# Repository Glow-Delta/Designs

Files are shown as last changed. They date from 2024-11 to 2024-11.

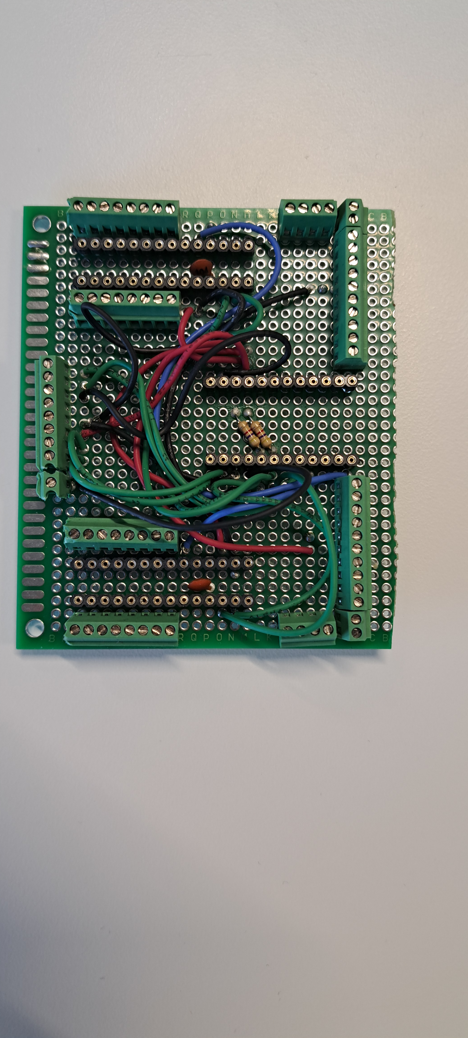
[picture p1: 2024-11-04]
Design Top component/20241104_130950.jpg

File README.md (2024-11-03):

# Designs
Repo for all the project design files, no code

When a design change is made it isn't final until its written down and reviewed. To submit a design change: make a new branch, commit the design changes and create a pull request into the main branch. Only after review has gone through will the change go through.

Designs to submit before monday 14:00:
-  [ ] Print board design
-  [ ] Updated C4
-  [ ] Network cableing
-  [ ] LED cylinder component
-  [ ] power supply component

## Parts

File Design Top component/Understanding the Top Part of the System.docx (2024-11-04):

Understanding the Top Part of the System: Movement Detection Module

Goal of the System

The primary goal of the top part of the system is to detect movement from end users using a series of sensors. This functionality allows the system to monitor and respond to changes in the environment based on user interaction or movement.

Components Inside

1. 16 Ultrasonic Sensors
  - These sensors are strategically positioned to cover a wide detection area. Each sensor is capable of emitting ultrasonic sound waves and measuring the time it takes for the waves to bounce back after hitting an object, enabling accurate distance measurements and movement detection.
2. Printed Circuit Board (PCB)
  - The printed circuit board acts as the foundation for connecting and integrating all electronic components. It ensures organized wiring and stable connectivity between sensors and microcontrollers.
3. Pro Micro Microcontroller
  - The Pro Micro serves as the main microcontroller, managing data collection from the sensors and processing input. It sends data through serial communication to the main server or the next processing stage.
4. MCP23017 I2C Port Expander
  - The MCP23017 is used to expand the number of general-purpose input/output (GPIO) pins available, as the Pro Micro itself has limited GPIO capability. This expander ensures that all 16 sensors can be connected and managed efficiently.

How It Works

1. Sensor Activation: Each of the 16 ultrasonic sensors is connected to the system through the PCB and controlled via the Pro Micro. These sensors emit ultrasonic pulses and wait for the return signal to measure the distance to any object in front of them.
2. Data Processing: The Pro Micro collects the distance data from the sensors. If movement is detected (i.e., a change in the distance data that indicates a user's presence or motion), the microcontroller processes this input.
3. GPIO Management: The MCP23017 I2C Port Expander plays a crucial role in handling the signals from all 16 sensors. By expanding the Pro Micro's limited number of GPIO pins, the MCP23017 allows simultaneous connections for all sensors without compromising data integrity.
4. Communication: Processed data from the Pro Micro is transmitted via serial communication to a server for further action. This data transfer ensures that detected movement can trigger various responses, such as activating alerts, updating displays, or executing other system operations.
5. LED Strip Activation: When movement is detected, the system also sends a signal to connected LED strips. These LED strips have a base animation that plays during standby. When movement is detected, the animation changes to a different pattern, providing visual feedback that the system has registered interaction.

Visual Representation

Below is a simplified diagram that illustrates the layout and connections of the components within the top part:

+-----------------------+

| Printed Circuit |

| Board |

+-----------------------+

| 16 Ultrasonic |

| Sensors |

+-----------------------+

| MCP23017 I2C |

| Port Expander |

+-----------------------+

| Pro Micro |

+-----------------------+

| LED Strips |

+-----------------------+

Summary

This top part of the system is designed to detect user movement efficiently with the help of 16 ultrasonic sensors, a Pro Micro microcontroller, and an MCP23017 port expander. The PCB ensures seamless connectivity among all components, enabling the module to function as an effective movement detection system. Additionally, the LED strips provide visual confirmation of movement detection with a change from the base animation to an active animation.

Understanding this setup helps in both troubleshooting and optimizing the system for enhanced detection performance.

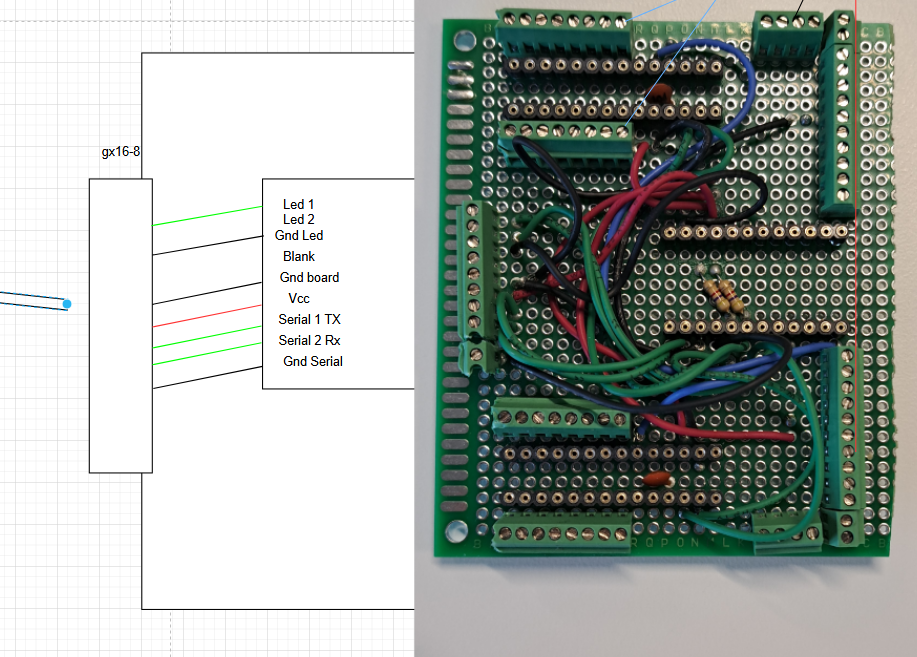
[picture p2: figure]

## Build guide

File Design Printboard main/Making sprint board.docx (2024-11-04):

Redesign Component board

2x mcp23017

1x pro micro

Output:

Led → 3 pin

Serial → 2 pin


eerst schetsen op het whiteboard, 2 schetsen, gekozen voor de 2de.

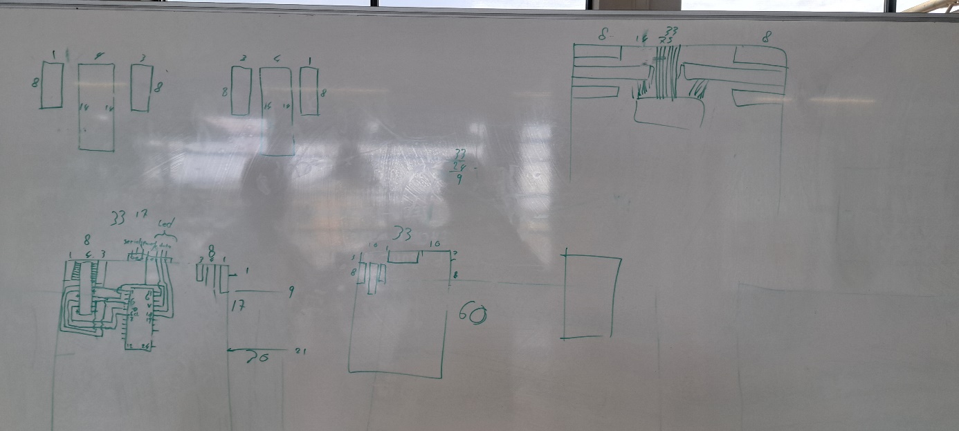
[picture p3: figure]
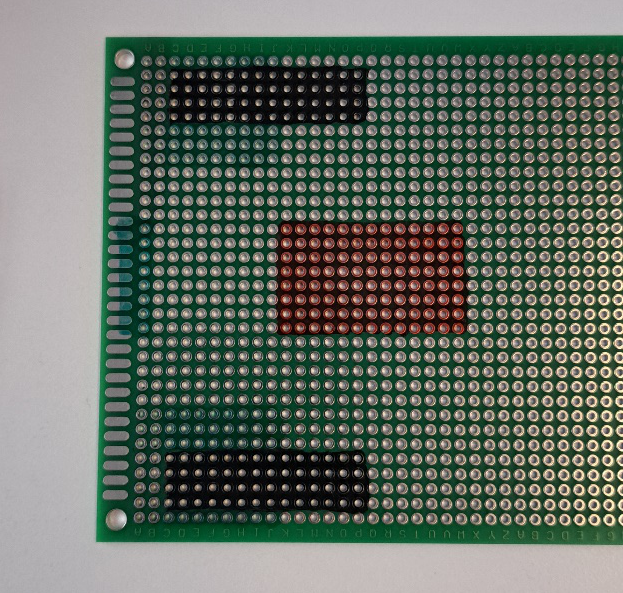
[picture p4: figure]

Daarna schetsen op fritzing

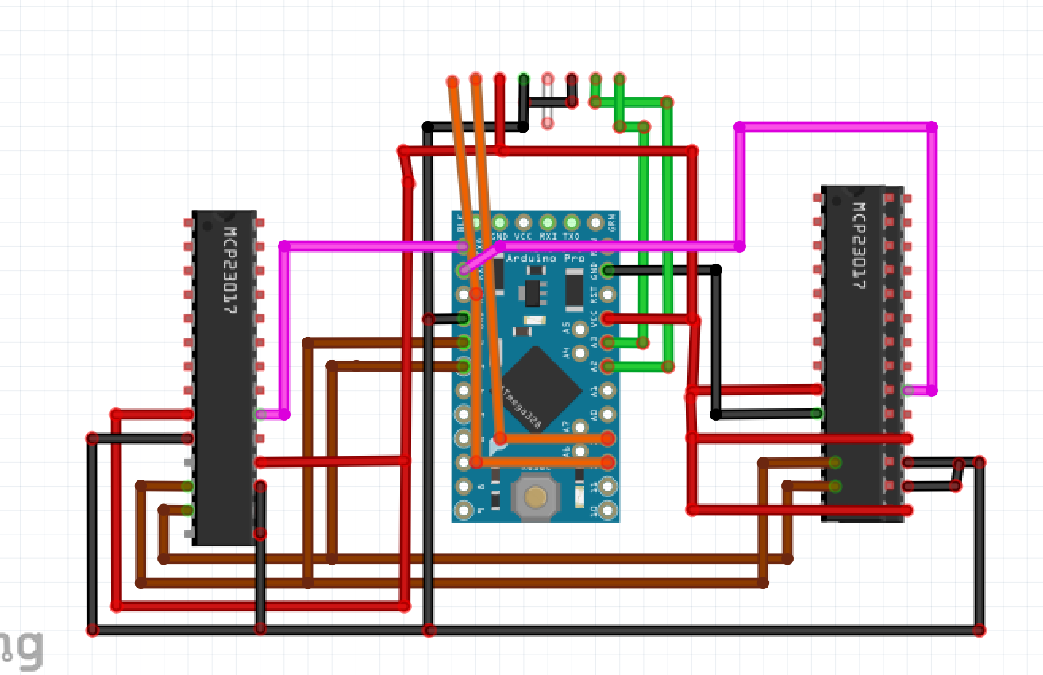
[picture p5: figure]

After some isuess with this design i needed to adjust it a little bit

- Before we used software serial, but that gives a lot of error in the board. Because interupt is going door the real serial ports. So we switched that.
- Added the positive and negative banks.
- Here i gave a single ground to every component. So that wont interfere.

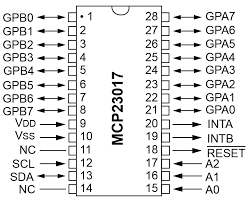
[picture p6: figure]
How To Use A MCP23017 I2C Port Expander With The Raspberry Pi - Part 1 - Raspberry Pi Spy
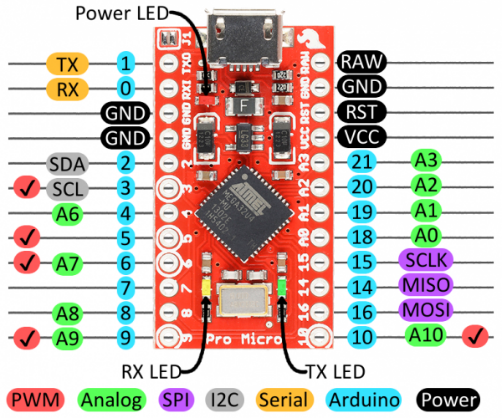
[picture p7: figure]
Pro Micro & Fio V3 Hookup Guide - SparkFun Learn
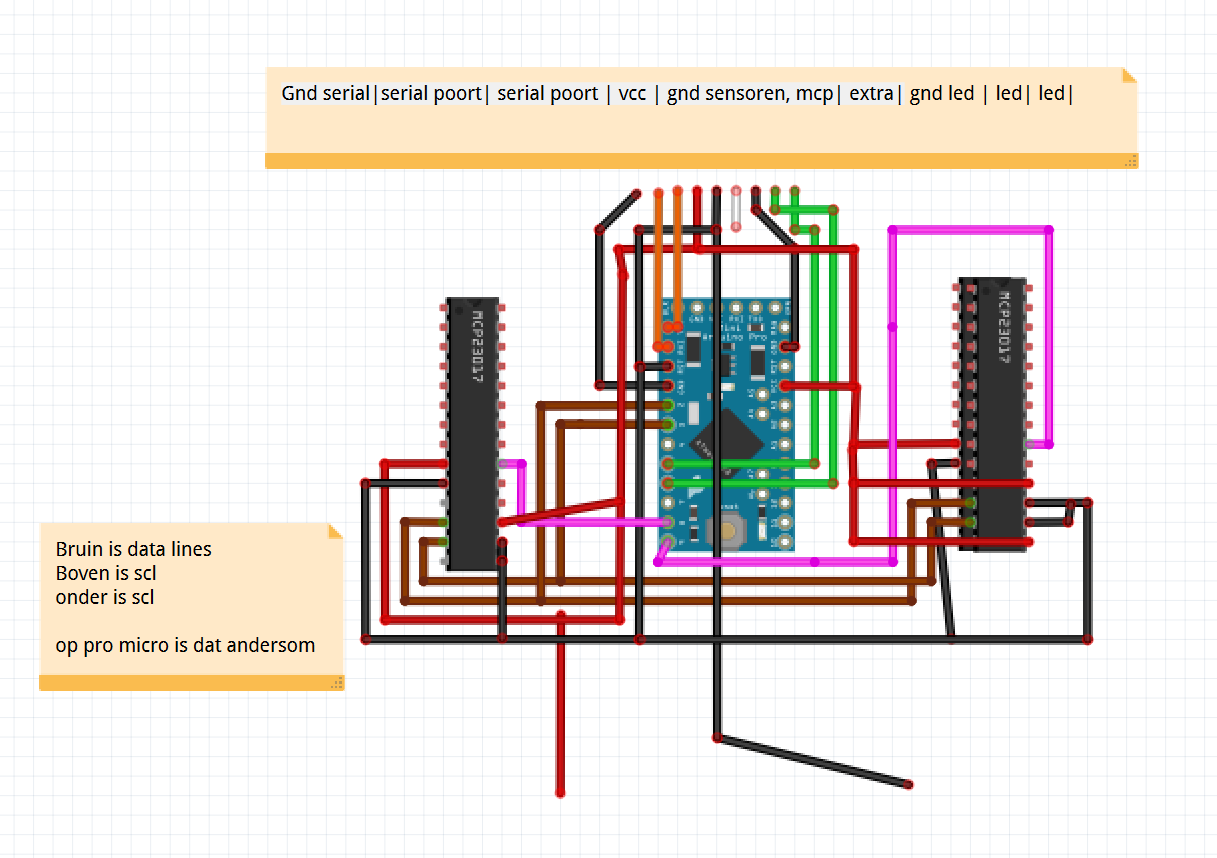
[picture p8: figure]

Schema maken van de onderkant…

Serial = 0,1

Led = 5,6

Interupt 8,9

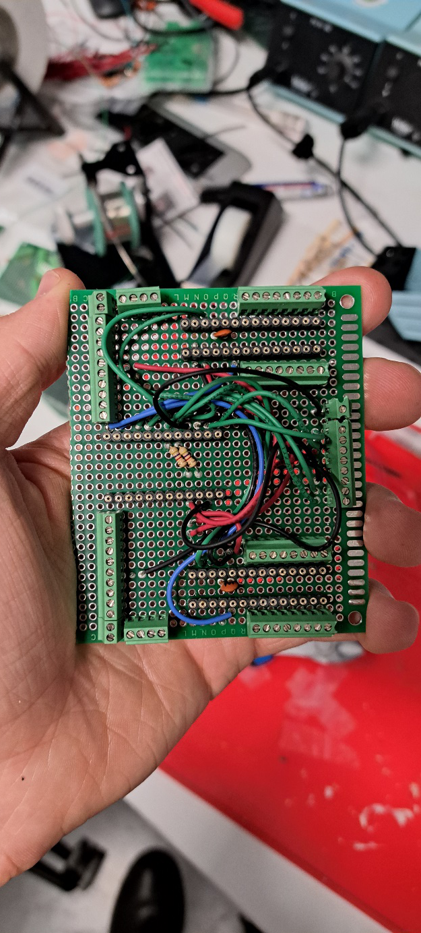
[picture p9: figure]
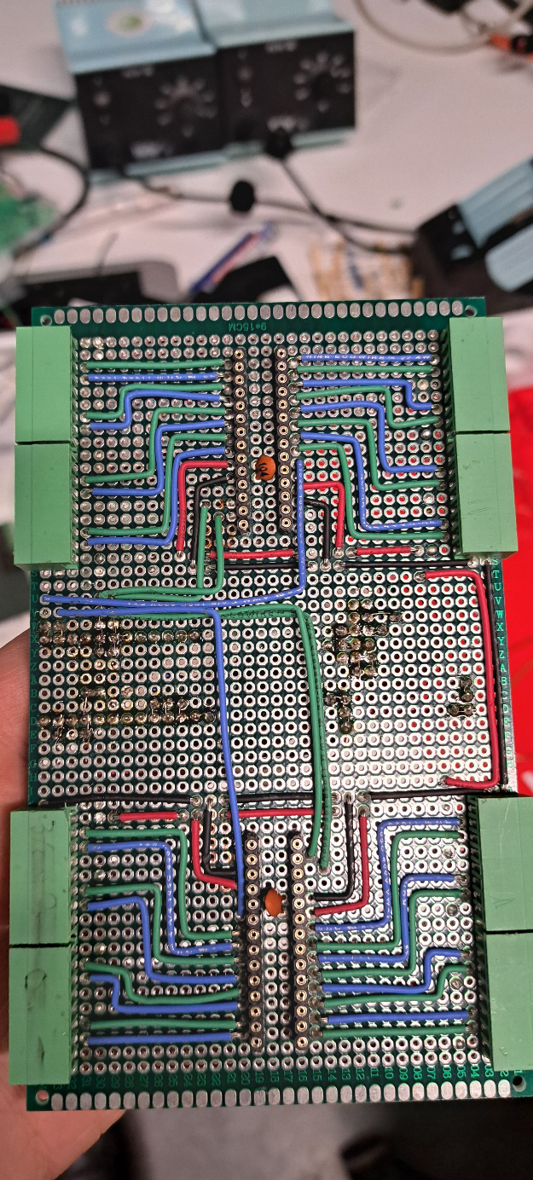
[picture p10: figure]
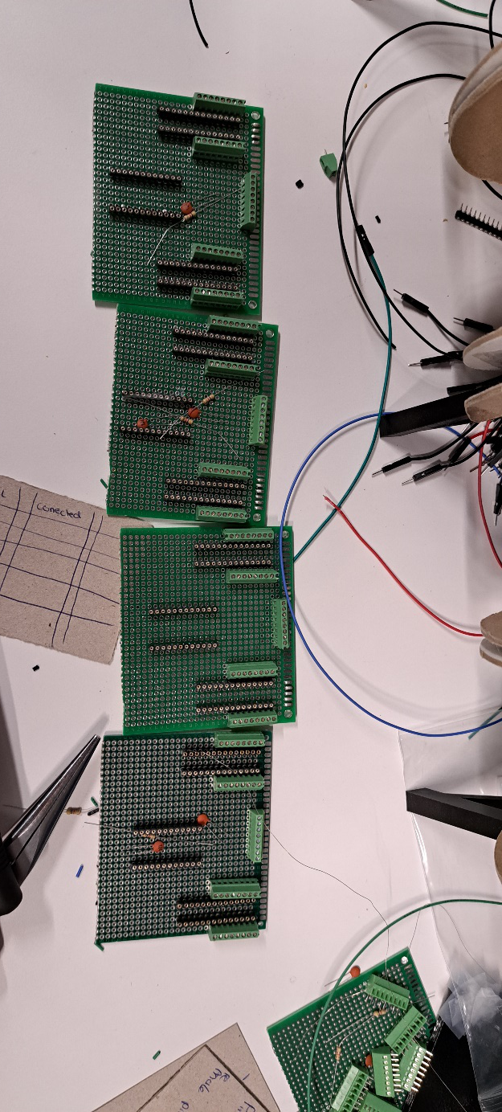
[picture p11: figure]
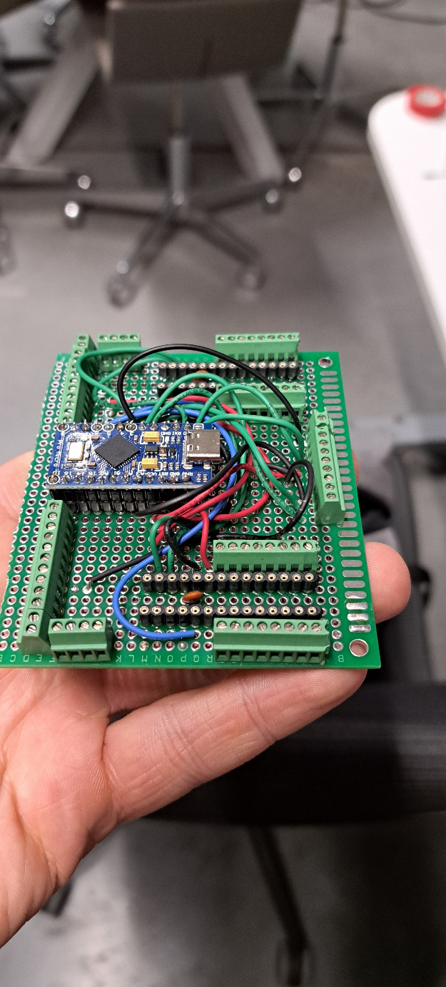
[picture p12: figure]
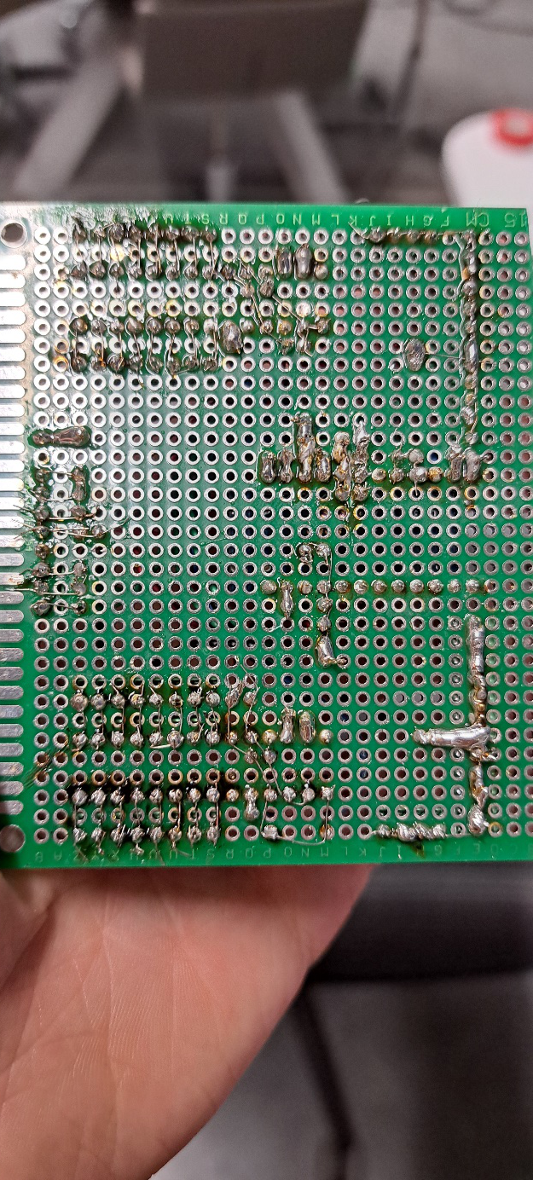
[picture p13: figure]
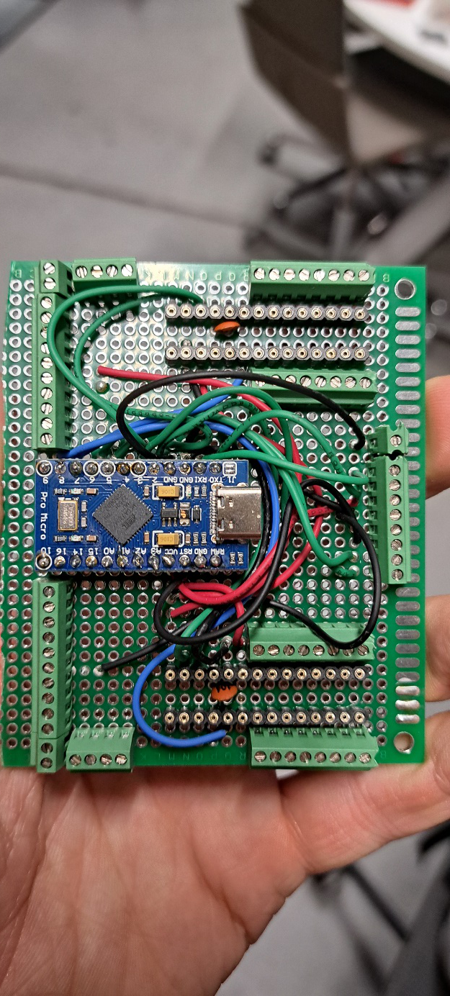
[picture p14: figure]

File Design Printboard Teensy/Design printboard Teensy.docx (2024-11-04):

Research Document: Design of Printboard for Teensy 4.0 with Serial Connection

1. Introduction The goal of this research is to design a printboard for a Teensy 4.0 microcontroller with considerations for managing voltage levels in serial communication. The setup is part of the project Glow, which requires accepting data from five different tubes via serial connections and transmitting this data to a server using UDP Ethernet. The design must handle voltage level shifting between 5V Pro Micro outputs and the 3.3V-compatible Teensy 4.0 to ensure safe and effective operation.

2. Components Overview The essential components required for the design of the printboard include:

- Teensy 4.0: A powerful microcontroller running at 3.3V logic levels.
- Pro Micro: A microcontroller operating at 5V logic levels.
- Resistors:
  - 20kΩ resistors
  - 10kΩ resistors

3. Voltage Level Shifting Since the Pro Micro operates at 5V and the Teensy 4.0 at 3.3V, it is necessary to lower the voltage on the serial lines (Tx) to prevent damage to the Teensy. This can be accomplished using a simple resistor divider circuit.

4. Resistor Divider Circuit Design The voltage divider formula is used to calculate the output voltage:

- Input Voltage (V_{in}): 5V from the Pro Micro.
- Target Output Voltage (V_{out}): 3.3V for compatibility with the Teensy 4.0.
- Chosen Resistors:
  - R1: 20kΩ
  - R2: 10kΩ

Using these values:

This output voltage is safe for the Teensy 4.0’s 3.3V logic level.

5. Component Connections

- Teensy 4.0: Central microcontroller unit.
  - Power/GND: Connected to a stable power source.
  - Ethernet Output: Connected for communication as needed to send data to the server via UDP.
  - Serial Inputs (5):
    - Tx and Rx Lines: Include voltage dividers to step down the voltage from the Pro Micro’s 5V outputs to 3.3V inputs.
    - GND: Common ground between Pro Micro and Teensy.

6. Design Layout The printboard layout should:

- Include space for the Teensy 4.0 and the associated resistor dividers.
- Ensure neat routing of serial connection traces (Tx, Rx) from Pro Micro units to the Teensy, incorporating the resistor dividers in the path.
- Designate separate lines for power and ground for clear signal integrity.
- Integrate Ethernet connections to facilitate data transmission to the server.

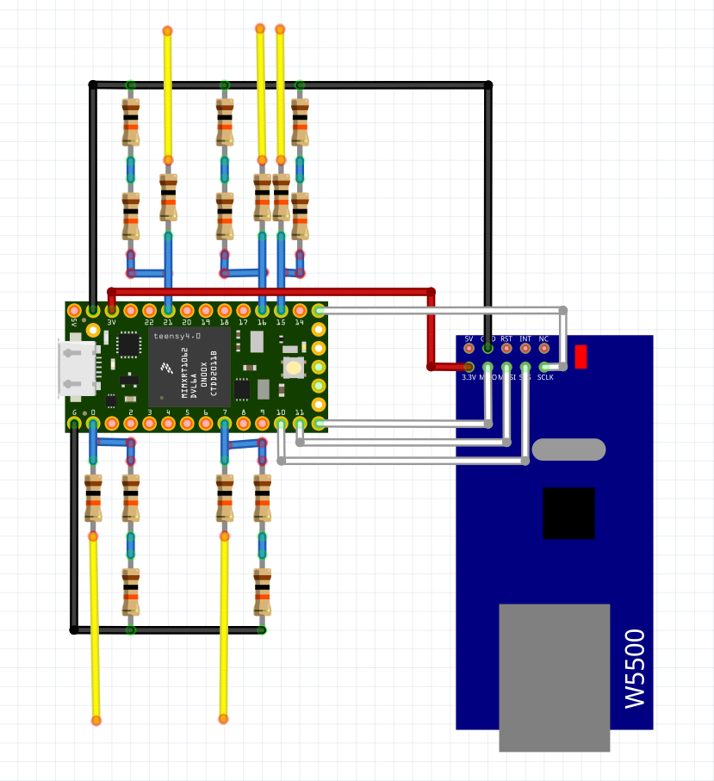
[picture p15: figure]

7. Assembly Notes

- Soldering Tips:
  - Resistors should be soldered firmly without cold joints to maintain signal consistency.
  - Verify connections with a multimeter for continuity and correct voltage output.
- Testing:
  - Power up the setup without the Teensy initially to test voltage outputs on the serial lines.
  - Confirm that the voltage does not exceed 3.3V on the Teensy input pins.

8. Conclusion By using the chosen resistor values (20kΩ and 10kΩ), the voltage on the serial connection can be safely stepped down from 5V to 3.3V, ensuring compatibility between the Pro Micro and Teensy 4.0. Proper assembly and layout will result in a reliable printboard for serial communication, capable of processing data from five tubes and sending it to the server via UDP Ethernet.

This research and design framework will guide the development of a secure and efficient printboard suitable for serial communication between the specified microcontrollers for the Glow project.

Attachment 1:

Pinout teensy.

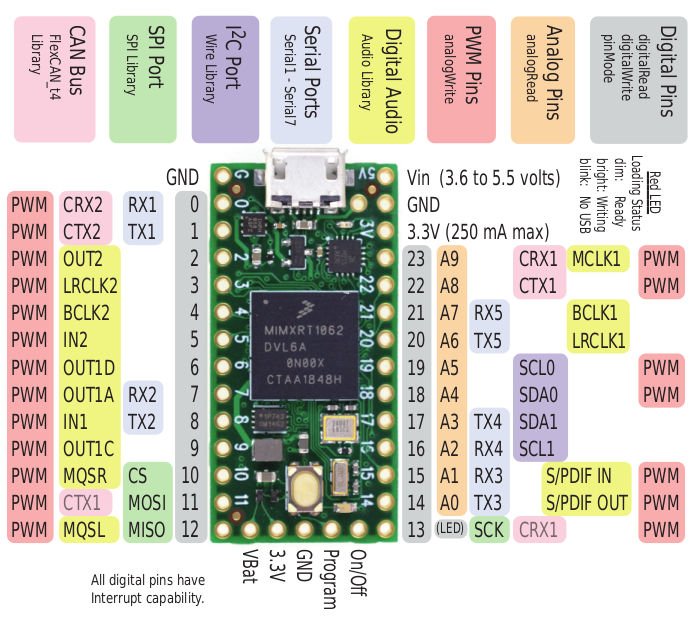
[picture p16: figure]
Teensy and Teensy++ Pinouts, for C language and Arduino Software

Attachment 2:

Pinout w5500 ethernet module.

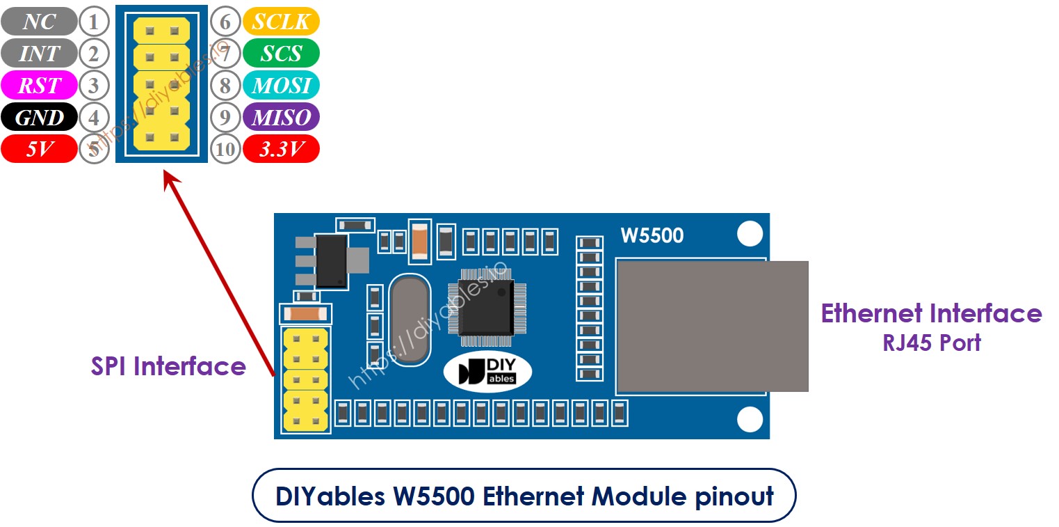
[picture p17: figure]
Arduino Nano - Ethernet | Arduino Nano Tutorial
